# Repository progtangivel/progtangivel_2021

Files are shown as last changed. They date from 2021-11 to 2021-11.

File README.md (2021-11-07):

# progtangivel_2021

Programação tangível é uma solução formada por peças que representam “pedaços” de código. Uma vez encaixadas, elas formam comandos que são executados por um robô ou computador. Ela permite que a programação seja manuseada, facilitando o processo didático.

Propomos o desenvolvimento de um projeto de programação tangível de baixo custo que possa ser acessado e reproduzido de forma aberta em qualquer lugar do país. Além disso, as ex-alunas Camila Farias (IME 09) e Lea Veras (IME 07), que lideram o projeto e são especialistas em educação, vão orientar o projeto no sentido de adequá-lo para o uso em um currículo alinhado com a BNCC e levando em consideração questões de acessibilidade (para estudantes portadores de deficiências).

Como resultado, vamos produzir um modelo para impressão em cortadora a laser e o código de programação, que serão disponibilizados gratuitamente. Dessa forma, educadores que quiserem utilizar essa ferramenta poderão acessar esse recurso de forma livre, precisando apenas adicionar os componentes eletrônicos. Esse projeto também poderá ser utilizado por iniciativas de alunos que queiram montar workshops e outras experiências educacionais como ação social.

## Alunos do IME Participantes:

Ana Luíza Buse Da Silva (IME 22 - Engenharia Elétrica)

Clarice Garnica Barros (IME 23 - Engenharia Química)

Yu Yi Wang Xia (IME 23 - Engenharia de Comunicações)

## Descritivo dos diretórios do projeto

### ArquivosMontagemCaixa 
Aqui se encontram os arquivos do CAD pra montagem da caixa leitora e um pequeno tutorial para montagem das peças e da caixa

### CodigoProcessamentoTangivel 

Aqui de fato se encontra o codigo .ino utilizado para ler e processar o codigo tangível

### CodigoTags 

Este diretório constitui arquivos .ino auxiliares pra formatar e cadastrar as tags tangíveis a serem utilizadas.

### libraries 

Neste diretório, encontram-se todas as bibliotecas que precisam ser importadas (basta importar essas bibliotecas na pasta libraries do Arduino) para funcionar o código.

Nesta pasta, está incluso também as duas bibiliotecas criadas ao longo do projeto:

**TangibleProcessTag.h**

**TangibleActions.h**

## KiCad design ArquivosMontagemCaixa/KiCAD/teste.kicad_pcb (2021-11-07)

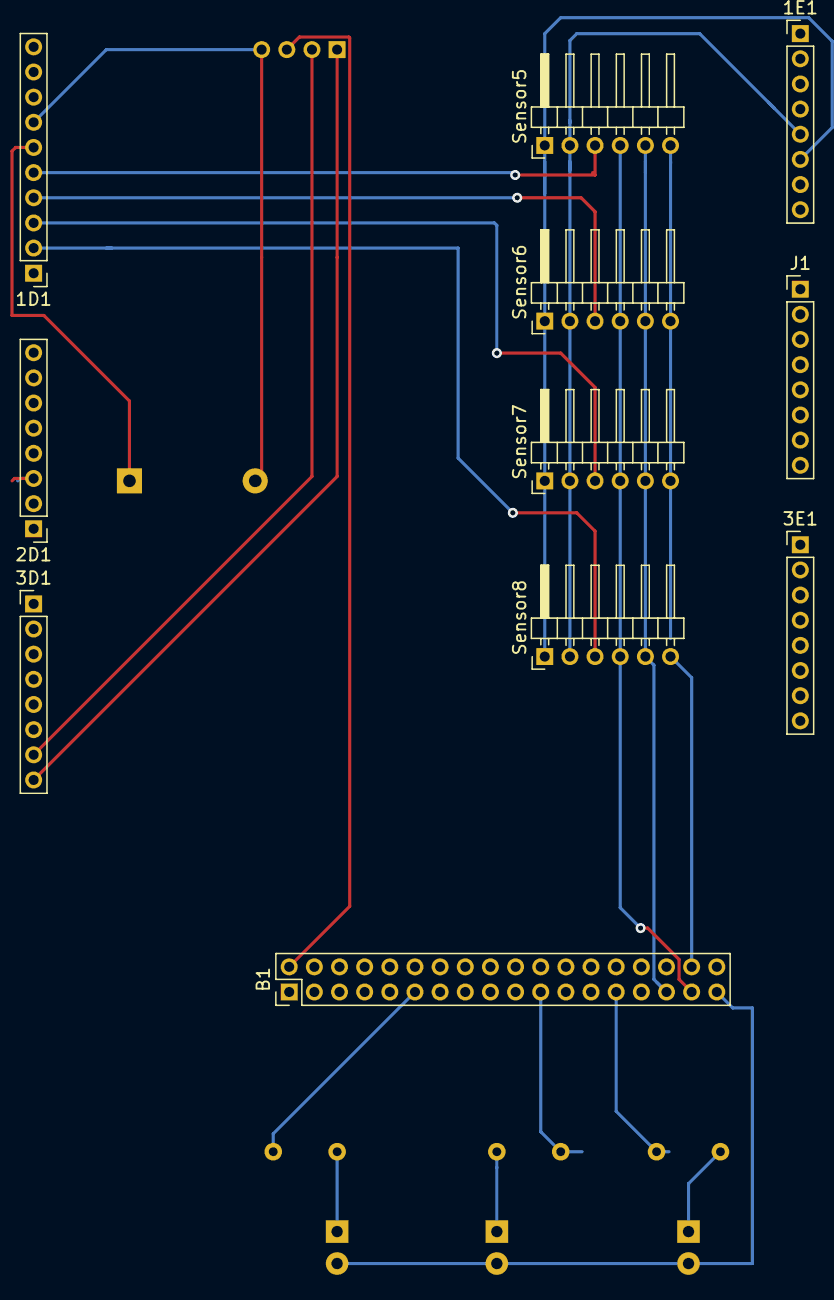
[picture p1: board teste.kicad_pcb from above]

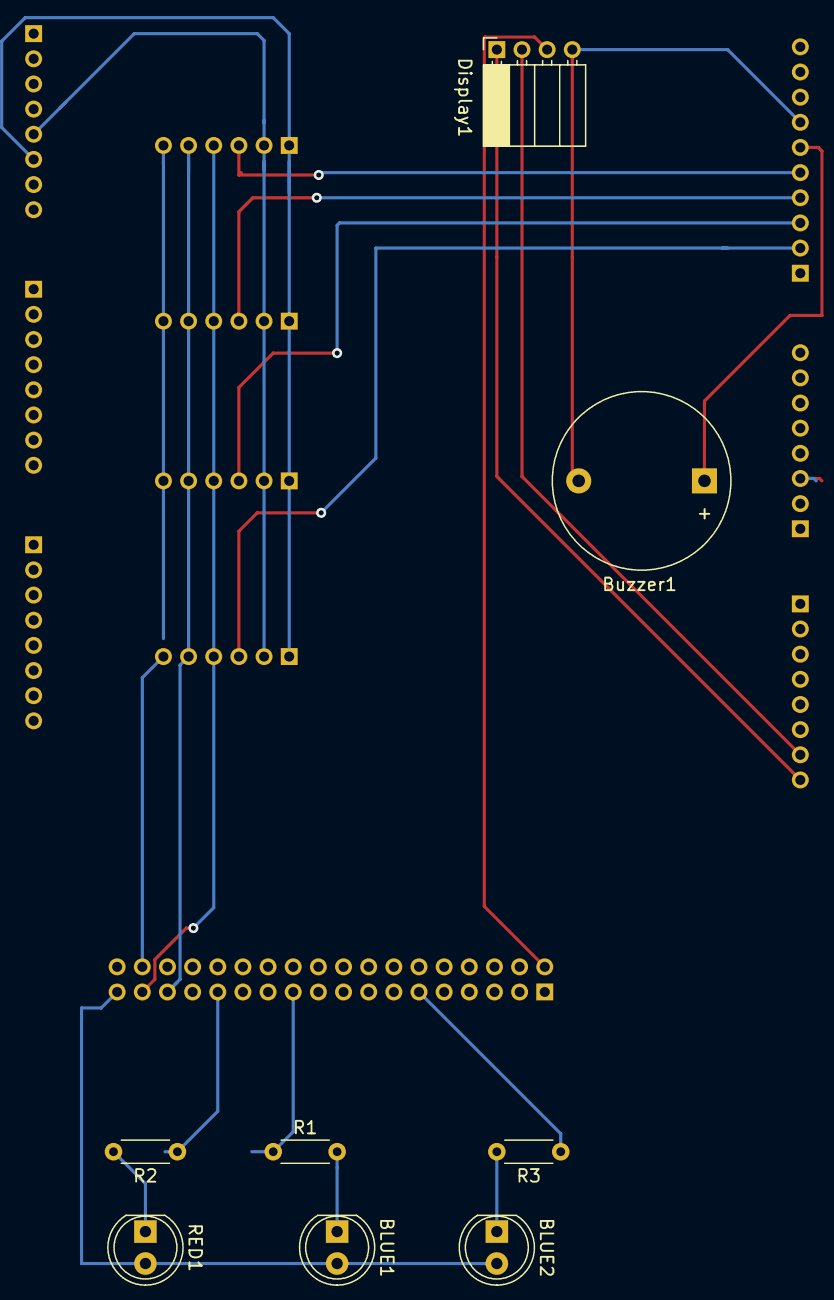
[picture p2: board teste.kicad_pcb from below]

Board: 2 copper layers, 19 parts (8 on the bottom side), 22 nets.

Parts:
1D1: Conn_01x10; PinHeader_1x10_P2.00mm_Vertical
1E1, 2D1, 3D1, 3E1: Conn_01x08; PinHeader_1x08_P2.00mm_Vertical
B1: Conn_02x18_Odd_Even; PinHeader_2x18_P2.00mm_Vertical
BLUE1, BLUE2: LED; LED_D5.0mm
Buzzer1: Buzzer; Buzzer_D14mm_H7mm_P10mm
Display1: .; PinSocket_1x04_P2.00mm_Horizontal
J1: Conn_01x08; PinHeader_1x08_P2.00mm_Vertical
R1, R2, R3: 220; R_Axial_DIN0204_L3.6mm_D1.6mm_P5.08mm_Horizontal
RED1: LED; LED_D5.0mm
Sensor5: Sensor 4; PinHeader_1x06_P2.00mm_Horizontal
Sensor6: Sensor 3; PinHeader_1x06_P2.00mm_Horizontal
Sensor7: Sensor 2; PinHeader_1x06_P2.00mm_Horizontal
Sensor8: Sensor 1; PinHeader_1x06_P2.00mm_Horizontal

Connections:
5V: 1E1.5, Sensor5.2, Sensor6.2, Sensor7.2, Sensor8.2
/13: 1D1.6, Buzzer1.1
/20: 3D1.7, Display1.2
/21: 3D1.8, Display1.1
GND: 1E1.6, Sensor5.1, Sensor6.1, Sensor7.1, Sensor8.1
MOSI: B1.33, Sensor5.4, Sensor6.4, Sensor7.4, Sensor8.4
unnamed: 1D1.7, Buzzer1.2, Display1.4
unnamed: B1.2, Display1.3
unnamed: B1.11, R3.1
unnamed: B1.21, R1.1
unnamed: B1.27, R2.1
unnamed: B1.31, Sensor5.5, Sensor6.5, Sensor7.5, Sensor8.5
unnamed: B1.34, Sensor8.6
unnamed: B1.35, BLUE1.2, BLUE2.2, RED1.2
unnamed: BLUE1.1, R1.2
unnamed: BLUE2.1, R3.2
unnamed: R2.2, RED1.1
unnamed: Sensor5.6, Sensor6.6, Sensor7.6
SS-sensor1: 1D1.2, Sensor8.3
SS-sensor2: 1D1.3, Sensor7.3
SS-sensor3: 1D1.4, Sensor6.3
SS-sensor4: 1D1.5, Sensor5.3

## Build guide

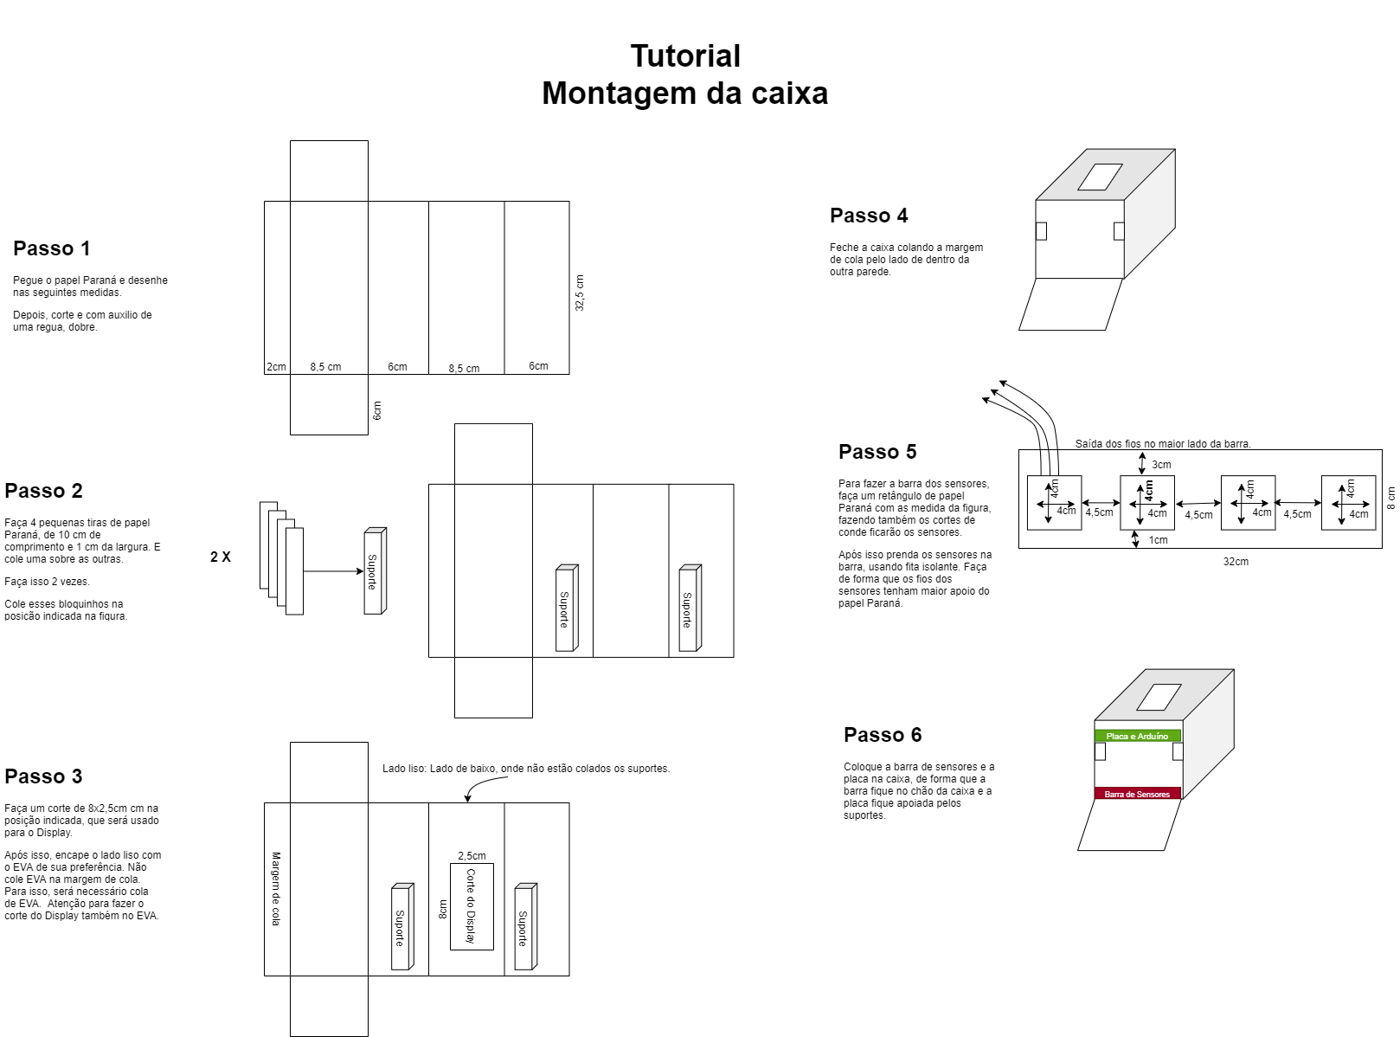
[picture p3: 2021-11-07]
ArquivosMontagemCaixa/caixa.drawio.png

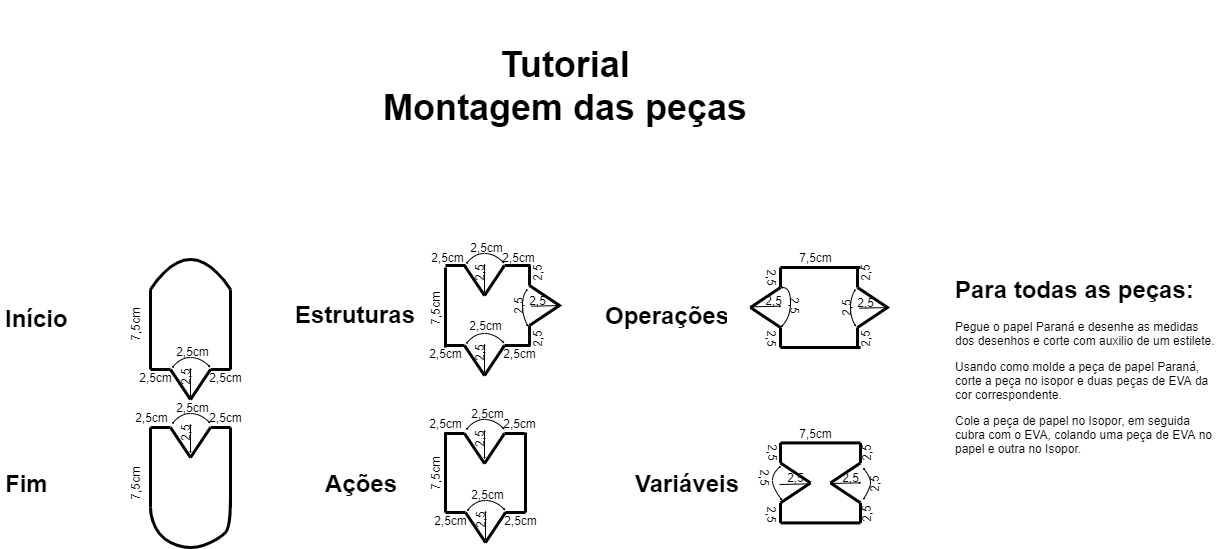
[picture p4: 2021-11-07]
ArquivosMontagemCaixa/peças.drawio.png

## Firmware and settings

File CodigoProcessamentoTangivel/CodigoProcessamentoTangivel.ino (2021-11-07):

#include <TangibleProcessTag.h>

#include <SPI.h>
#include <PN532_SPI.h>
#include <PN532.h>
#include <NfcAdapter.h>

#include <ArduinoSTL.h>
#include <Arduino.h>

#include <map>
#include <vector>

#define READERS 4 // Numero de READERS da matriz de Leitura

String multiarray[100][4];
String columnA, columnB, columnC;

ProcessTag Project;

int currentRow = 1;

void processMatrix(String matrix[][4])
{
  int totalRows = currentRow;
  int a[totalRows][READERS];

  Serial.println("Início do processamento");
  Serial.println("Matriz para ser processada:");
  for (int i = 0; i < currentRow; i++)
  {
    for (int j = 0; j < 3; j++)
    {
      Serial.print(i);
      Serial.print(",");
      Serial.print(j);
      Serial.print(":");
      Serial.println(multiarray[i][j]);
      
      String aux = multiarray[i][j];
      aux.remove(aux.length() - 2);
      a[i][j] = aux.toInt();
    }
  }
  Serial.println("Execução do Código:");

  Project.runCode(a, 1, totalRows);
}

PN532_SPI pn532spiA(SPI, 9);
NfcAdapter nfcA = NfcAdapter(pn532spiA);

PN532_SPI pn532spiB(SPI, 10);
NfcAdapter nfcB = NfcAdapter(pn532spiB);

PN532_SPI pn532spiC(SPI, 12);
NfcAdapter nfcC = NfcAdapter(pn532spiC);

void setup(void)
{
  Project.setupLCD();

  Serial.begin(9600);
  Serial.println("* Verificação Modulos PN532 NFC RFID *");
  nfcA.begin();
  nfcB.begin();
  nfcC.begin();
}

void loop(void)
{
  columnA = "";
  columnB = "";
  columnC = "";

  delay(400);

  Serial.println("\nScan row of NFC tags\n");

  if (nfcA.tagPresent(200))
  {
    NfcTag tagA = nfcA.read();
    //tagA.print();

    if (tagA.hasNdefMessage())
    {
      NdefMessage messageA = tagA.getNdefMessage();
      NdefRecord recordA = messageA.getRecord(0);

      int payloadLengthA = recordA.getPayloadLength();
      byte payloadA[payloadLengthA];
      recordA.getPayload(payloadA);

      String payloadAsStringA = "";
      for (int c = 0; c < payloadLengthA; c++)
      {
        payloadAsStringA += String((char)payloadA[c]);
      }
      Serial.println(payloadAsStringA);
      columnA = payloadAsStringA;
    }
  }
  delay(200);

  if (nfcB.tagPresent(200))
  {
    NfcTag tagB = nfcB.read();
    //tagB.print();

    if (tagB.hasNdefMessage())
    {
      NdefMessage messageB = tagB.getNdefMessage();
      NdefRecord recordB = messageB.getRecord(0);

      int payloadLengthB = recordB.getPayloadLength();
      byte payloadB[payloadLengthB];
      recordB.getPayload(payloadB);

      String payloadAsStringB = "";
      for (int c = 0; c < payloadLengthB; c++)
      {
        payloadAsStringB += String((char)payloadB[c]);
      }
      Serial.println(payloadAsStringB);
      columnB = payloadAsStringB;
    }
    delay(200);
  }

  if (nfcC.tagPresent(200))
  {
    NfcTag tagC = nfcC.read();
    //tagB.print();
    if (tagC.hasNdefMessage())
    {
      NdefMessage messageC = tagC.getNdefMessage();
      NdefRecord recordC = messageC.getRecord(0);

      int payloadLengthC = recordC.getPayloadLength();
      byte payloadC[payloadLengthC];
      recordC.getPayload(payloadC);

      String payloadAsStringC = "";
      for (int c = 0; c < payloadLengthC; c++)
      {
        payloadAsStringC += String((char)payloadC[c]);
      }
      Serial.println(payloadAsStringC);
      columnC = payloadAsStringC;
    }
    delay(200);
  }

  if (columnA != "")
  {
    multiarray[currentRow][0] = columnA;
    if (columnB != "")
    {
      multiarray[currentRow][1] = columnB;
      if (columnC != "")
      {
        multiarray[currentRow][2] = columnC;
      }
    }

    // Se o primeiro termo da currentRow analisa for diferente do primeiro termo da proxima currentRow analisada
    if (multiarray[currentRow][0] != multiarray[currentRow - 1][0])
    {
      currentRow++;
      delay(100);
      Serial.println("Row scanned!");
      // Se for a tag de FIM, finaliza o programa
      if (columnA == "99900")
      {
        Serial.println("Scanning finished! Compiling tangible code!");
        processMatrix(multiarray);
      }
    }
    else
    { // Se ainda estiver lendo a mesma currentRow, capture a column B e C.
      if (columnB != "")
      {
        multiarray[currentRow - 1][1] = columnB;
      }

      if (columnC != "")
      {
        multiarray[currentRow - 1][2] = columnC;
      }

      Serial.println("New row not detected");
    }
  }

  delay(1000);
}

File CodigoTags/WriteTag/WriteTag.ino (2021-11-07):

#include <SPI.h>
#include <PN532_SPI.h>
#include <PN532.h>
#include <NfcAdapter.h>

PN532_SPI pn532spi(SPI, 10);
NfcAdapter nfc = NfcAdapter(pn532spi);


void setup() {
      Serial.begin(9600);
      Serial.println("NDEF Writer");
      nfc.begin();
}

void loop() {
    Serial.println("\nPlace a formatted Mifare Classic or Ultralight NFC tag on the reader.");
    if (nfc.tagPresent()) {
        NdefMessage message = NdefMessage();
        message.addUriRecord("20300");

        bool success = nfc.write(message);
        if (success) {
          Serial.println("Success. Try reading this tag with your phone.");        
        } else {
          Serial.println("Write failed.");
        }
    }
    delay(5000);
}

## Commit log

2021-11-07 Added KiCAD files to project
    [teste.kicad_pcb, teste.sch]
2021-11-07 Addded drawio files and assembly tutorial files
2021-11-07 Changed folders setup
    [teste.kicad_pcb, teste.sch]
2021-11-07 Added Tags files + Changes folder structure
    [teste.kicad_pcb, teste.sch]
